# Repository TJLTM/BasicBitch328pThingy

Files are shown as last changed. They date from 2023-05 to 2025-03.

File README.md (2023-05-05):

# BasicBitch328pThingy

This is a basic Bitch. 
Made with the Atmel 328p DIP model 
Has 3 Buffered inputs
Has 3 VDC outputs 
Pulled out the remaining pins for 
ability to add other things. I'd 
rate the Outputs ~ 1A a piece 
but probably shouldn't do that 
traces won't handle it. Design 
it for triggering 12 volt 
relays.

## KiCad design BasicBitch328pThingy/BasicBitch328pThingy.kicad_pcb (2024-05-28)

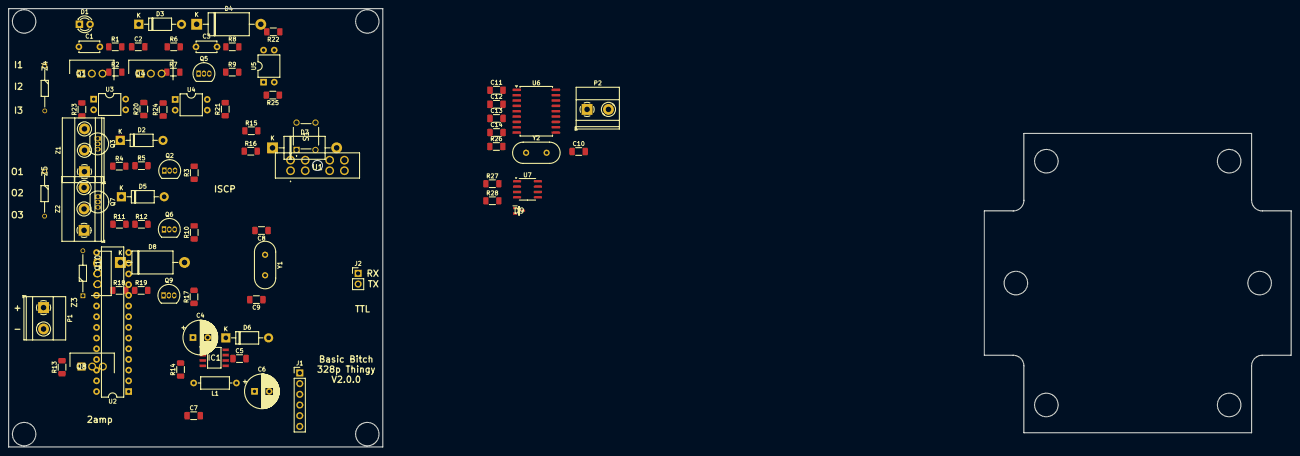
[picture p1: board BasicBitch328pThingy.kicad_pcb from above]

Board: 2 copper layers, 88.9 x 104.1 mm, 82 parts (0 on the bottom side), 59 nets, no tracks yet.

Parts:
C1, C3: 0.1uF; C_Disc_D4.7mm_W2.5mm_P5.00mm
C2, C13, C14: 100nf; C_1206_3216Metric_Pad1.33x1.80mm_HandSolder
C4: 68uF; CP_Radial_D8.0mm_P3.50mm
C5, C7: 22pF; C_1206_3216Metric_Pad1.33x1.80mm_HandSolder
C6: 120uF; CP_Radial_D8.0mm_P3.50mm
C8, C9, C10: 220nF; C_1206_3216Metric_Pad1.33x1.80mm_HandSolder
C11, C12: 22pf; C_1206_3216Metric_Pad1.33x1.80mm_HandSolder
D1: LED; LED_D3.0mm
D2: 1N5817; D_DO-41_SOD81_P10.16mm_Horizontal
D3, D5, D6: 1N4007; D_DO-41_SOD81_P10.16mm_Horizontal
D4, D7, D8: STPS3150RL; D_DO-201_P15.24mm_Horizontal
D9: PESD5V0L2UU,115; SOT65P210X110-3N
IC1: LM2597MX-5.0_NOPB; SOIC127P600X175-8N
J1: TTL_Programmer; PinHeader_1x06_P2.54mm_Vertical
J2: Conn_01x02; PinHeader_1x02_P2.54mm_Vertical
L1: 150uH; L_Axial_L6.6mm_D2.7mm_P10.16mm_Horizontal_Vishay_IM-2
P1, P2: Screw_Terminal_01x02; TerminalBlock_Phoenix_MKDS-1,5-2-5.08_1x02_P5.08mm_Horizont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
Q1, Q4, Q8, Q10: IRF9Z34NPBF; TO254P469X1042X1967-3P
Q2, Q3, Q5, Q6, Q7, Q9: 2N7000; TO-92_Inline
R1, R4, R11, R22, R25, R26: 10k; R_1206_3216Metric_Pad1.30x1.75mm_HandSolder
R2, R3: 330; R_1206_3216Metric_Pad1.30x1.75mm_HandSolder
R5, R12, R16: 470; R_1206_3216Metric_Pad1.30x1.75mm_HandSolder
R6, R7, R8, R13, R14, R15, R17, R18, R19: 5k; R_1206_3216Metric_Pad1.30x1.75mm_HandSolder
R9, R20, R23: 1M; R_1206_3216Metric_Pad1.30x1.75mm_HandSolder
R10, R21, R24: 100k; R_1206_3216Metric_Pad1.30x1.75mm_HandSolder
R27: 17k; R_1206_3216Metric_Pad1.30x1.75mm_HandSolder
R28: 120; R_1206_3216Metric_Pad1.30x1.75mm_HandSolder
S1: TS02-66-160-BK-260-LCR-D; TS0266160BK260LCRD
U1: 178.6165.0001; 17861650001
U2: ATmega328-P; DIP-28_W7.62mm
U3, U4, U5: LTV-817; DIP-4_W7.62mm
U6: MCP2515-xSO; SOIC-18W_7.5x11.6mm_P1.27mm
U7: MCP2551-I-SN; SOIC-8_3.9x4.9mm_P1.27mm
Y1: Crystal; Crystal_HC49-U_Vertical
Y2: 16MHz; Crystal_HC49-U_Vertical
Z1, Z2: Screw_Terminal_01x03; TerminalBlock_Phoenix_MKDS-1,5-3-5.08_1x03_P5.08mm_Horizont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
Z3, Z4, Z5: BZX79C10; DIOAD1068W53L380D172

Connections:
+5V: C6.1, C13.1, C14.1, IC1.3 (BIAS_SUPPLY), IC1.4 (FEEDBACK), J1.3, L1.2, R2.1, R7.1, R8.1, R14.1, R15.1, R18.1, R19.1, R26.2, U2.7 (VCC), U2.20 (AVCC), U2.21 (AREF), U6.18 (VDD), U7.3 (VDD)
+VDC: C4.1, IC1.7 (+VIN), Q4.3, Q8.3, Q10.3, R4.1, R10.1, R21.1, R24.1, U1.1, U1.2, U1.7, U1.8, Z3.1, Z4.1, Z5.1
/CANBUS-MCP2515/RXtoCANTC: U6.2 (RXCAN), U7.4 (RXD)
/CANBUS-MCP2515/TXtoCANTC: U6.1 (TXCAN), U7.1 (TXD)
/CANBUS-MCP2551/CANH: D9.1 (CATHODE_1), J2.1, P2.2, U7.7 (CANH)
/CANBUS-MCP2551/CANL: D9.2 (CATHODE_2), P2.1, R28.2, U7.6 (CANL)
/Input1/Input: C9.1, D5.1 (K), R12.1, Z2.2
/Input2/Input: C10.1, D6.1 (K), R16.1, Z2.3
/Input/Input: C8.1, D3.1 (K), R5.1, Z2.1
/Output1/Output: D7.1 (K), Q8.2, Z1.2
/Output2/Output: D8.1 (K), Q10.2, Z1.3
/Output/Output: D4.1 (K), Q4.2, Z1.1
D8: U2.14 (PB0), U6.12 (~INT)
D10: U2.16 (PB2), U6.16 (~CS)
GND: C1.2, C3.2, C4.2, C5.2, C6.2, C7.2, C8.2, C9.2, C10.2, C11.2, C12.2, C13.2, C14.2, D2.2 (A), D4.2 (A), D7.2 (A), D8.2 (A), D9.3 (COMMON_ANODE), IC1.6 (GROUND), J1.1, P1.2, Q2.1 (S), Q3.1 (S), Q5.1 (S), Q6.1 (S), Q7.1 (S), Q9.1 (S), R1.2, R3.2, R6.2, R9.2, R13.2, R17.2, R20.2, R23.2, R27.2, S1.3 (COM_1), U2.8 (GND), U2.22 (GND), U3.3, U4.3, U5.3, U6.9 (VSS), U7.2 (VSS)
Input1: R8.2, U2.5 (PD3), U3.4
Input2: R15.2, U2.6 (PD4), U4.4
Input3: R19.2, U2.4 (PD2), U5.4
LED: D1.2 (A), U2.13 (PD7)
MISO: U2.18 (PB4), U6.15 (SO)
MOSI: U2.17 (PB3), U6.14 (SI)
unnamed: D1.1 (K), R3.1
unnamed: D2.1 (K), IC1.8 (OUTPUT), L1.1
unnamed: D3.2 (A), Q2.2 (G), R5.2, R6.1
unnamed: D5.2 (A), Q5.2 (G), R12.2, R13.1
unnamed: D6.2 (A), Q6.2 (G), R16.2, R17.1
unnamed: C1.1, IC1.2 (DELAY)
unnamed: IC1.1 (ERROR_FLAG), R4.2
unnamed: C3.1, IC1.5 (~SHUTDOWN/SOFT-START)
unnamed: C2.1, J1.6
unnamed: J2.2, R28.1
unnamed: P1.1, Q1.2
unnamed: Q1.1, R1.1
unnamed: Q1.3, U1.3, U1.4, U1.5, U1.6
unnamed: Q2.3 (D), U3.2
unnamed: Q3.3 (D), R11.2
unnamed: Q4.1, R10.2, R11.1, Z3.2
unnamed: Q5.3 (D), U4.2
unnamed: Q6.3 (D), U5.2
unnamed: Q7.3 (D), R22.2
unnamed: Q8.1, R21.2, R22.1, Z4.2
unnamed: Q9.3 (D), R25.2
unnamed: Q10.1, R24.2, R25.1, Z5.2
unnamed: R7.2, U3.1
unnamed: R14.2, U4.1
unnamed: R18.2, U5.1
unnamed: C5.1, U2.9 (XTAL1/PB6), Y1.1
unnamed: C7.1, U2.10 (XTAL2/PB7), Y1.2
unnamed: C12.1, U6.8 (OSC1), Y2.1
unnamed: C11.1, U6.7 (OSC2), Y2.2
unnamed: R26.1, U6.17 (~RESET)
unnamed: R27.1, U7.8 (Rs)
Output1: Q3.2 (G), R9.1, U2.11 (PD5)
Output2: Q7.2 (G), R20.1, U2.12 (PD6)
Output3: Q9.2 (G), R23.1, U2.15 (PB1)
RXttl: J1.4, U2.2 (PD0)
Reset: R2.2, S1.1 (NO_1), U2.1 (~RESET/PC6)
SCK: U2.19 (PB5), U6.13 (SCK)
TXttl: J1.5, U2.3 (PD1)

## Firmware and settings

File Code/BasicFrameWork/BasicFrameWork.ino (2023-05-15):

#define Input1
#define Input2
#define Input3
#define Output1
#define Output2
#define Output3
#define LED


void setup() {
  pinMode(Input1, INPUT);
  pinMode(Input2, INPUT);
  pinMode(Input3, INPUT);
  pinMode(Output1, OUTPUT);
  pinMode(Output2, OUTPUT);
  pinMode(Output3, OUTPUT);
  pinMode(LED, OUTPUT);

}

void loop() {


}

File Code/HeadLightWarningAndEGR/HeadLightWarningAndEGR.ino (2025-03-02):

#define HeadLight
#define EngineRun
#define Input3
#define DingDong
#define EGR
#define Output3
#define LED

long EGRTimer, WarningTimer;
bool DelayEGR, WarningDelay = false;

void setup() {
  pinMode(HeadLight, INPUT);
  pinMode(EngineRun, INPUT);
  pinMode(Input3, INPUT);
  pinMode(DingDong, OUTPUT);
  pinMode(EGR, OUTPUT);
  pinMode(Output3, OUTPUT);
  pinMode(LED, OUTPUT);
  digitalWrite(DingDong, LOW);
  digitalWrite(EGR, LOW);
  digitalWrite(Output3, LOW);
  digitalWrite(LED, LOW);
}


void loop(){
  bool EngineStatus = digitalRead(EngineRun);

  if (digitalRead(HeadLight) == LOW && digitalRead(EngineRun) == HIGH) {
    digitalWrite(LED,HIGH);
    digitalWrite(DingDong, HIGH);
  }
  else {
    digitalWrite(LED,LOW);
    digitalWrite(DingDong, LOW);
  }
  
}


void Oldloop() {
  bool EngineStatus = digitalRead(EngineRun);

  if (digitalRead(HeadLight) == LOW && EngineStatus == HIGH) {
    digitalWrite(LED,HIGH);
    if (WarningDelay == false) {
      WarningDelay = true;
      WarningTimer = millis();
    }
    if (millis() - WarningDelay > 5000) {
      digitalWrite(DingDong, HIGH);
    }
  }
  else {
    digitalWrite(LED,LOW);
    digitalWrite(DingDong, LOW);
  }


  if (EngineStatus == LOW) {
    if (digitalRead(EGR) == HIGH) {
      if (DelayEGR == false) {
        DelayEGR = true;
        EGRTimer = millis();
      }
      if (millis() - EGRTimer > 300000) {
        digitalWrite(EGR, HIGH);
      }
    }
  }
  else {
    digitalWrite(EGR, LOW);
  }
}

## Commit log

2023-05-01 initial design
    [CarHeadlightBuzzer.kicad_pcb, CarHeadlightBuzzer.kicad_sch, input.kicad_sch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]
2023-05-03 some routing
    [CarHeadlightBuzzer.kicad_pcb, CarHeadlightBuzzer.kicad_sch, input.kicad_sch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]
2023-05-03 post routed and switched out the crystal needs to be inspected
    [CarHeadlightBuzzer.kicad_pcb, CarHeadlightBuzzer.kicad_sch]
2023-05-03 last bits of stuff
    [CarHeadlightBuzzer.kicad_pcb]
2023-05-03 rename of folder
    [BasicBitch328pThingy.kicad_pcb, BasicBitch328pThingy.kicad_sch, input.kicad_sch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]
2023-05-03 adding fab files pcbway zip
2023-05-15 V1.0.1
    * Fixed a trace issue
    * updated Fab Files
    * added bom/ibom.html
    * added some code
    ** BasicFrameWork.ino
    ** Test.ino
    ** HeadLightWarningAndEGR.ino
    [BasicBitch328pThingy-B_Cu.gbr, BasicBitch328pThingy-B_Mask.gbr, BasicBitch328pThingy-B_Paste.gbr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]
2023-05-20 updating to have the correct pin outs.
    [BasicFrameWork.ino, HeadLightWarningAndEGR.ino, Test.ino]
2024-05-28 revamping this to have a CANBus Interface and swaping things to a SMD to save Space.
    [BasicBitch328pThingy.kicad_pcb, BasicBitch328pThingy.kicad_sch, CANBUS-MCP2515.kicad_sch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]
2025-03-02 Revert "updating to have the correct pin outs."
    This reverts commit a5202e797f862cd26f941edca5d2a58ef8195523.
    [BasicFrameWork.ino, HeadLightWarningAndEGR.ino, Test.ino]
